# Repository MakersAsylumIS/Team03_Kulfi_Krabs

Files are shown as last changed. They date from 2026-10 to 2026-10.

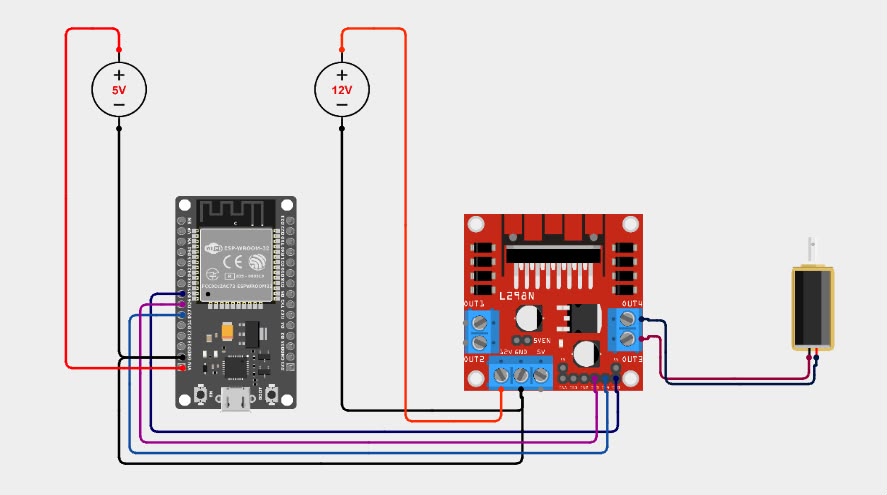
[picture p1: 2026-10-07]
Photos_Videos/Images/WhatsApp Image 2026-10-07 at 11.19.05 AM.jpeg

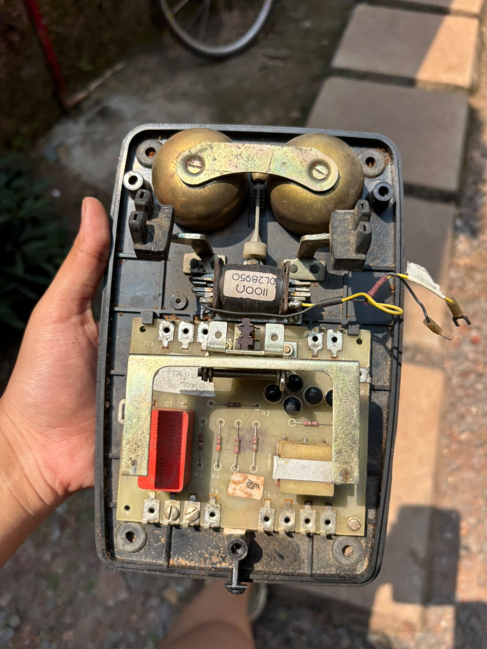
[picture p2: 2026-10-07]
Photos_Videos/Images/WhatsApp Image 2026-10-07 at 11.19.09 AM.jpeg

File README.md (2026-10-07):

# MAKER'S ASYLUM + KULFI Play it Forward (PiF) Partnership
## 2026 Week 40 COHORT 06
## Team : KULFI_RABS

Describe the project.
Describe what are the contents of each folder - CODE, CAD, Electronics etc

## License

Licenses

<a href="LICENSE.md">Open Source Licenses Facts</a>

#### Hardware
CERN Open Hardware License Version 2 - Strongly Reciprocal ([CERN-OHL-S-2.0](https://spdx.org/licenses/CERN-OHL-S-2.0.html)).

#### Software
MIT open source [license](http://opensource.org/licenses/MIT).

#### Documentation:
<br />This work is licensed under a <a rel="license" href="http://creativecommons.org/licenses/by/4.0/">Creative Commons Attribution 4.0 International License</a>.

---

## 📬 Contact/Team

> _List team members and contact emails or GitHub profiles._
[@anool](https://github.com/Anool)
> 
>
> ---

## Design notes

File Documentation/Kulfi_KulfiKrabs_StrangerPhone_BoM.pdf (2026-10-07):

Year | 2026
Cohort | Kulfi Collective
Team Name | Kulfi Krabs
Project Name | Stranger Phone
Team Members | Khushi | Devashree
Email IDs
Team Mentor | Kushal Bhor
Team Mentor

Project Brief:

Sr no | Product name | Qty
| 1 Vintage push-button telephone (Bakelite / BSNL style) with handset, cord, keypad and hook

1

2 12 mm tactile push
buttons (pack of 10)

1

Notes
* Use this template and fill in the details below. Share it back with "editable" link.
* Explain your project in brief

* For all the components (https://robu.in/) that you are ordering online provide the reference link of the online store from where you are
* For the components that you are planning to purchase from your local store provide the reference link of image or video
* DO NOT RELY ON GETTING ANYTHING FROM THE LOCAL STORE HERE IN GOA. YOU WON'T HAVE THE TIME, MEANS OR AVAILABILITY TO GET THE COMPONENTS FROM THE LOCAL STORE
A vintage push-button telephone mounted inside a Mumbai kaali-peeli cab. A passenger picks up the handset, chooses a language (1 English / 2 Hindi / 3 Marathi), hears a short description in that language, then presses 4 to hear a message a previous stranger left, or 5 to record one for the next stranger (6 to re-record, 7 to save). Messages are stored on a microSD card by language and played back only to listeners who chose that language. After saving, the passenger taps their phone on an NFC sticker for a small web 'surprise'. Built on an ESP32-A1S Audio Kit (records + plays audio, SD card, onboard keys); powered by a power bank. Pillars from fieldwork: empathy, connection, time.

3 Micro limit switch
with lever (2 pcs)

1

4 Ai-Thinker ESP32-A1S
Audio Kit v2.2
(ES8388 codec,
microSD, 6 keys,
headphone + speaker

2

5 microSD card 32 GB
Class 10 (HP mi210)

1

6 USB microSD card
reader

1

7 MAX9814 microphone
amplifier module
with electret
capsule (AGC)

2

8 Electret microphone
capsule 6 mm / 9 mm
(pack of 10)

1

9 Resistor assortment
kit (1/4 W, 50
values, 500 pcs)

1

10 3.5 mm AUX male-tomale cable (cut in
half for two
solderable plugs)

1

11 Mini speaker 8 Ohm
0.5 W, 28 mm (2 pcs)

1

12 4-core flexible
cable, 1 m (or spare
coiled handset cord)

1

13 NFC sticker tags
NTAG213 (pack of 10)

1

14 Power bank 10,000
mAh (EVM EnBolt
22.5W)

1

15 Micro-USB DATA
cable, 1.5 m (2 pcs)

1

16 Hookup wire 22 AWG,
5 colours x 2 m

1

17 Female-female Dupont
jumper wires, 20 cm
(40 pcs)

1

18 Male pin header
strip 2.54 mm (1 pc,
40 pins)

1

19 Heat-shrink tubing
assortment

1

20 Hot glue sticks (10)
+ double-sided foam
tape

1

21 Acrylic base plate
200 x 200 x 3 mm +
4x M4 bolts/nuts +
cable ties

1

22 Rubber grommet 8-10
mm (2 pcs)

1

Prices and stock checked on 25 Sep 2026 (Probots, Robu, Amazon.in): every link is a direct product page that was IN STOCK at the time of checking. Phone price depends on Chor Bazaar bargaining and is the lever if the total runs over. Online orders placed by 26 Sep reach Mumbai by 29 Sep (use the Mumbai pincode at checkout, not Goa). Nothing is being bought in Goa.

TOOLS TO CARRY (owned / borrowed, not purchased - add ~Rs 1,500 if any must be bought)
- Soldering iron (25-40 W) + solder + flux
- Wire stripper / cutter
- Multimeter (continuity for hook switch + keypad tracing)
- Small screwdriver set (phone screws) + hand drill or drill bits for the base plate
- Hot glue gun
- Laptop with Arduino IDE, ESP32 board package, arduino-audio-tools library and CP210x USB driver installed and tested BEFORE leaving
- NFC-capable phone with the 'NFC Tools' app (to write the URL to the tags)

PREP BEFORE GOA (the flowchart cannot run without these - no purchase needed)
- Record the prompt files as 16 kHz mono WAV: ask_lang (trilingual, 1 file) + for EACH of en/hi/mr: desc, menu, heres, none_yet, rec_intro ('record your message in <language> after the beep'), review (6/7), last_take, saved, surprise, goodbye, plus beep.wav = 32 files

- Record 5+ seed messages per language into archive/en, archive/hi, archive/mr so the first listener never hears 'no messages yet'
- Build and host the surprise web page (he/she/they -> emoji + cab location + time); free hosting (GitHub Pages / Netlify); write its URL with cab number to the NFC tags
- Flash and test the firmware on the bench with the full flow (language -> description -> listen / record -> 6 / 7 -> save -> hang-up resets to idle) before packing -including the power-bank keep-alive: Wi-Fi radio left on + 47 ohm resistor across 5V/GND, then leave it running on the bank overnight to prove the bank does not switch off
- Pre-drill the base plate; pack the spare board, spare SD card (pre-loaded) and spare mic module

Angad

Category | Purpose | Reference link
Electro-mechanical | Flow: 'Picks up the
| phone', keys 1-7,
| 'Hangs up'. Shell,
| handset (mic +
| earpiece), keypad, | https://www.olx.in/i
| | tems/q-vintage-
| | telephone (https://www.olx.in/items/q-vintage-telephone)
Electronics | Flow: keys 1-7. BACKUP: most push- button phones have a printed keypad matrix that cannot

https://robu.in/prod
uct/12x12x12mmtactile-push-buttonswitch-10pcs/ (https://robu.in/product/12x12x12mm-tactile-push-button-switch-10pcs/)

Electro-mechanical Flow: 'Picks up' / 'Hangs up'. BACKUP hook switch if the phone's original cradle contacts are

https://robu.in/prod
uct/kw1-103-z2a100-
spdt-short-levermicro-switch1n/ (https://robu.in/product/kw1-103-z2a100-spdt-short-lever-micro-switch1n/)
Electronics | The brain for every node: plays language/description /menu/record/review/ saved prompts from

https://probots.co.i
n/esp32-a1s-audiodevelopment-boardkit-ai-thinkerwifi.html (https://probots.co.in/esp32-a1s-audio-development-board-kit-ai-thinker-wifi.html)
Electronics | Flow: every prompt file (prompts/en, hi, mr) and the message archive (archive/en, hi,

https://www.amazon.i
n/dp/B07DJLFMPS (https://www.amazon.in/dp/B07DJLFMPS)
Electronics | Loading the 15 prompt WAV files and seed messages onto the SD card from a laptop, and pulling

https://www.amazon.i
n/dp/B0D9H3W8V6 (https://www.amazon.in/dp/B0D9H3W8V6)
Electronics | Flow: '(person records message)'. Sits inside the handset mouthpiece; AGC evens out

https://robu.in/prod
uct/max9814-highperformancemicrophone-agcamplifier-module-cma- (https://robu.in/product/max9814-high-performance-microphone-agc-amplifier-module-cma-4544pf-w/)
Electronics | FALLBACK mic: if the MAX9814 signal is too hot or noisy, a bare capsule soldered straight to

https://w (https://robu.in/product/max9814-high-performance-microphone-agc-amplifier-module-cma-4544pf-w/)ww.amazon.i
n/Yellow-Tommy-Condenser-Microphone-Directional/dp/B0GTQ
Z9ZNK (https://www.amazon.in/Yellow-Tommy-Condenser-Microphone-Directional/dp/B0GTQZ9ZNK)
Electronics | 10 kOhm pull-up for key 1 on IO36 (input- only pin); 10k/1k divider between MAX9814 and MIC1;

https://www.amazon.i
n/dp/B0D6LRHHVZ (https://www.amazon.in/dp/B0D6LRHHVZ)
Electronics | Flow: every 'hears' node. Carries audio OUT of the board's 3.5 mm headphone jack to the handset

https://robu.in/prod
uct/aux3-5mm-audioextension-cable-2mmale-to-male-grey/ (https://robu.in/product/aux3-5mm-audio-extension-cable-2m-male-to-male-grey/)

Electronics | Replacement earpiece only if the phone's original earpiece is dead. Driven from the headphone jack.

https://robu.in/prod
uct/0-5w-8ohmtrumpet-speakerdiameter-28mm/ (https://robu.in/product/0-5w-8ohm-trumpet-speaker-diameter-28mm/)
Electronics | BACKUP handset cord: mic V+, mic signal, earpiece, shared ground. Old coiled cords are often

https://robu.in/prod
uct/22awg-multicoreinsulated-cable4-
cores-silicone/ (https://robu.in/product/22awg-multicore-insulated-cable4-cores-silicone/)
Electronics | Flow: 'Taps on the NFC tag'. Stuck on the phone body; holds the URL of the surprise web page

https://www.amazon.i
n/Robodo-Sticker-13-
56MHz-ISO14443A-Ntag213/dp/B07DDDGT1
L (https://www.amazon.in/Robodo-Sticker-13-56MHz-ISO14443A-Ntag213/dp/B07DDDGT1L)
Electronics | Powers the board in the cab via micro- USB; driver swaps/charges it. Must NOT auto-shut-

https://www.amazon.i
n/dp/B0H1QCZ87F (https://www.amazon.in/dp/B0H1QCZ87F)
Electronics | One for programming the board from a laptop, one from the power bank in the cab.

https://www.amazon.i
n/dp/B082LZGK39 (https://www.amazon.in/dp/B082LZGK39)
Electronics | Wiring the 7 keys + hook switch to IO36, IO13, IO19, IO23, IO18, IO5, IO21, IO22 and the handset

https://www.amazon.i
n/dp/B0H8358SGS (https://www.amazon.in/dp/B0H8358SGS)
Electronics | Quick connections from the board's pin header to the switch wires during testing.

https://robu.in/prod
uct/20cm-dupont-wirecolor-jumper-cable-2-
54mm-1p-1p-female-female-40pcs/ (https://robu.in/product/20cm-dupont-wire-color-jumper-cable-2-54mm-1p-1p-female-female-40pcs/)
Electronics | In case the A1S header pins arrive unpopulated or you need extra pins to solder to.

https://robu.in/prod
uct/2-54mm-1x40-pinmale-single-rowstraight-long-headerstrip-pack-of-3/ (https://robu.in/product/2-54mm-1x40-pin-male-single-row-straight-long-header-strip-pack-of-3/)

Misc | Insulating every solder joint on the handset and keypad wiring.

https://www.amazon.i
n/dp/B08S3TP2Q6 (https://www.amazon.in/dp/B08S3TP2Q6)
Misc | Fixing the board, mic module and SD card inside the phone shell so nothing rattles in

https://www.amazon.i
n/dp/B0FD456NSD (https://www.amazon.in/dp/B0FD456NSD)
Mechanical | Mounts the phone in the cab: phone screws to the plate, plate cable-ties to the seat frame /

https://www.amazon.i
n/dp/B0DPV3BKWF (https://www.amazon.in/dp/B0DPV3BKWF)
Mechanical | Where the power cable exits the phone base.

https://www.amazon.i
n/Rebower-Rubber-Grommets-Flexible-Wire/dp/B0BN472J62 (https://www.amazon.in/Rebower-Rubber-Grommets-Flexible-Wire/dp/B0BN472J62)

Additional details | Cost
LOCAL: Chor Bazaar (Mutton St) or OLX Mumbai. Test hook switch, keypad and earpiece before buying. Buy by 28 Sep. | Rs 2,500

Robu pack of 10, Rs 49, in stock (checked 25 Sep).

Rs 49

Robu KW1-103 short-lever, Rs 14 each, in stock (checked 25 Sep). Order 2.

Rs 28

In stock at Probots, Rs 2,499 each, dispatch 1 working day, 1-3 day express to Mumbai. Alt: Amazon.in 'ESP32-Audio-Kit ESP32-A1S' (Rakstore / JESSINIE). ORDER BY 26

Rs 4,998

Amazon.in HP 32 GB Class 10 U1, Rs 899, in stock (checked 25 Sep). Card prices are high online right now - a local mobile shop is ~Rs 400-500; buy the 2nd (spare) card there if

Rs 899

Amazon.in Digitek DCR-007, USB-A 3.0 + Type-C, Rs 299, in stock (checked 25 Sep).

Rs 299

Robu Rs 191 each, in stock (checked 25 Sep). Alt:
https://www.sunrom.com/p/max9814-microphone-amplifier-agc-auto-gaincontrol . Order by 26 Sep.

Rs 382

Amazon.in Yellow Tommy pack of 10, Rs 249 (team-verified listing). Same capsule type also on Lamington Road.

Rs 249

Amazon.in AVS 500 pc assorted kit, Rs 199, in stock (checked 25 Sep). Robu resistor kits were all out of stock. Also cheap at Lamington Road.

Rs 199

Robu AUX 2 m cable, Rs 279-299, in stock - but overpriced. Any Rs 60-100 aux cable from a mobile shop / Lamington Road does the same job. Cut in half = two solderable plugs.

Rs 60

Robu 28 mm 0.5 W 8 ohm, Rs 39, IN STOCK (checked 25 Sep). Buy 2: one spare earpiece, one bench test speaker. The 36 mm version is out of stock.

Rs 78

Robu 22 AWG 4-core silicone cable, Rs 87 per metre, IN STOCK (checked 25 Sep). The 26/24/30 AWG versions are out of stock.

Rs 87

Amazon.in Robodo 10-pack. Alt in stock at Robu, Rs 29 per tag (checked 25 Sep):
https://robu.in/product/13-56-mhzntag213-144byte-sticker-nfc-tag/ .

Rs 300

Amazon.in EVM EnBolt 10000 mAh, Rs 749, in stock (checked 25 Sep). No low-current mode - so firmware keeps Wi-Fi on + a 47 ohm 1 W keep-alive resistor across 5V/GND (from the

Rs 749

Amazon.in Ambrane 3A braided micro-USB DATA cable 1.5 m, Rs 149, in stock (checked 25 Sep). Order 2 (one for programming, one for the cab).

Rs 298

Amazon.in SixOhms 22 AWG solid-core kit, 5 colours x 2 m, Rs 99, in stock (checked 25 Sep). Robu hook-up wire kits are out of stock / Rs 800+. Lamington Road sells by the

Rs 99

Robu 20 cm F-F 40 pcs, Rs 44, in stock (checked 25 Sep). The M-M/M-F/F-F combo pack is out of stock.

Rs 44

Robu pack of 3, Rs 15, in stock (checked 25 Sep).

Rs 15

Amazon.in Rpi Shop 80 pc assorted kit, Rs 165, in stock (checked 25 Sep). Robu alt in stock:
https://robu.in/product/colorfulheat-shrink-tubing-hst-insulation-

Rs 165

Amazon.in ProKart 7 mm glue sticks, 10 pcs, Rs 72, in stock (checked 25 Sep). Add double-sided foam tape from any stationery shop (~Rs 60).

Rs 132

Amazon.in black acrylic 200 x 200 x 3 mm, Rs 203, in stock (checked 25 Sep). M4 bolts/nuts + cable ties from any hardware shop (~Rs 100). Pre-drill before Goa.

Rs 303

Amazon.in Rebower 8 mm grommets, 20 pcs. Any hardware shop also has these.

Rs 20

TOTAL | Rs 11,953
Budget | Rs 12,000
Remaining | Rs 47

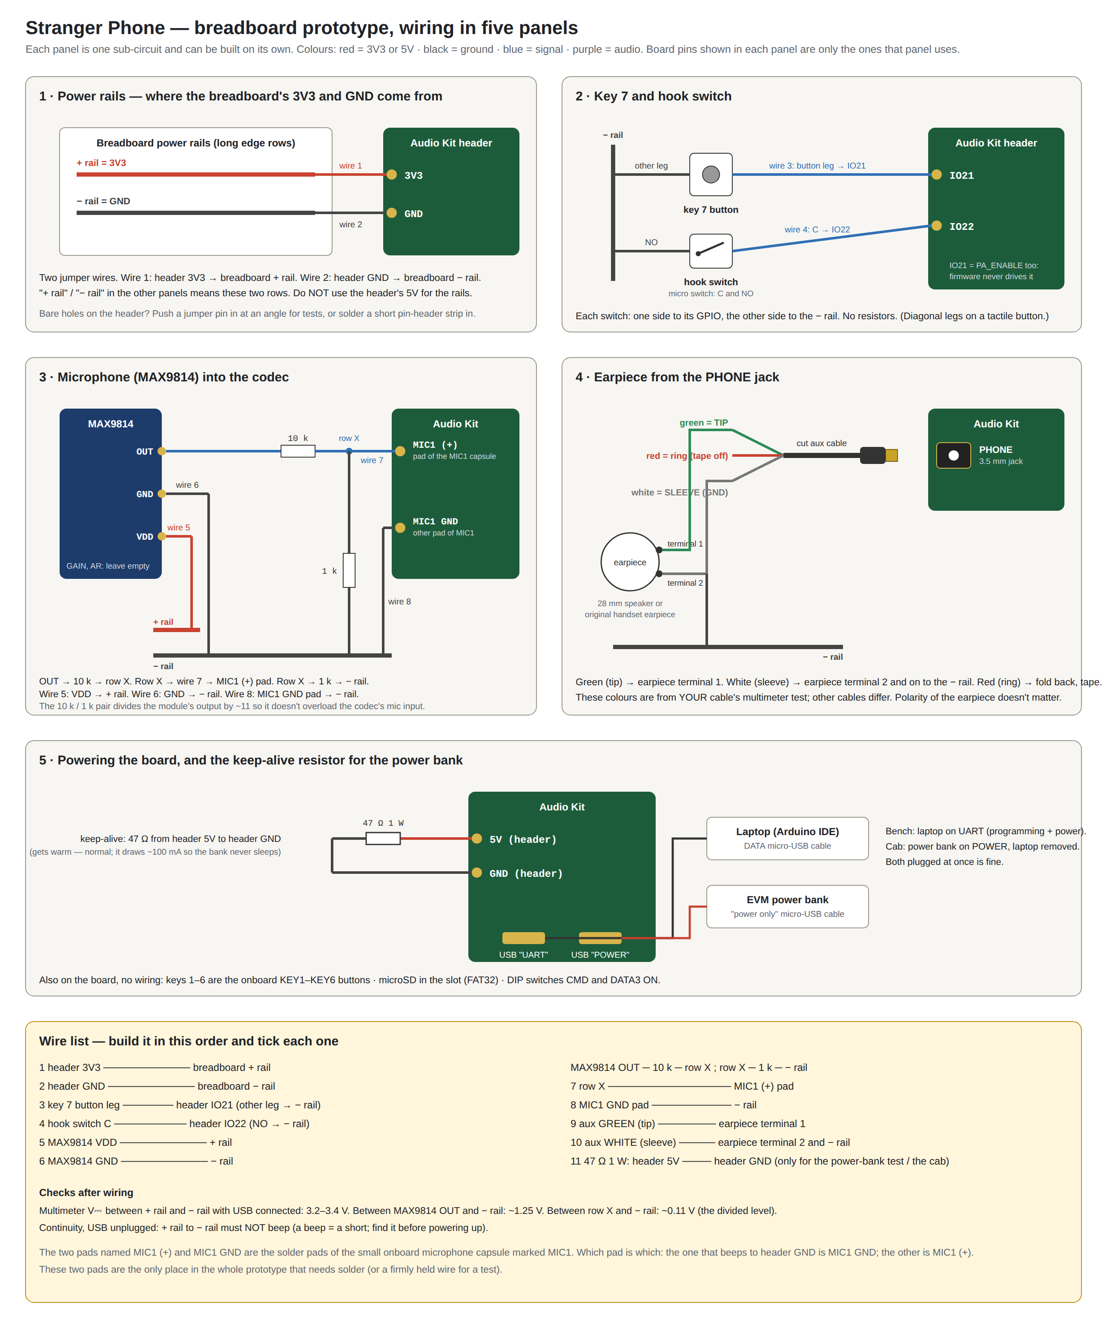
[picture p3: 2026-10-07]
Documentation/StrangerPhone_breadboard_schematic_v2.png

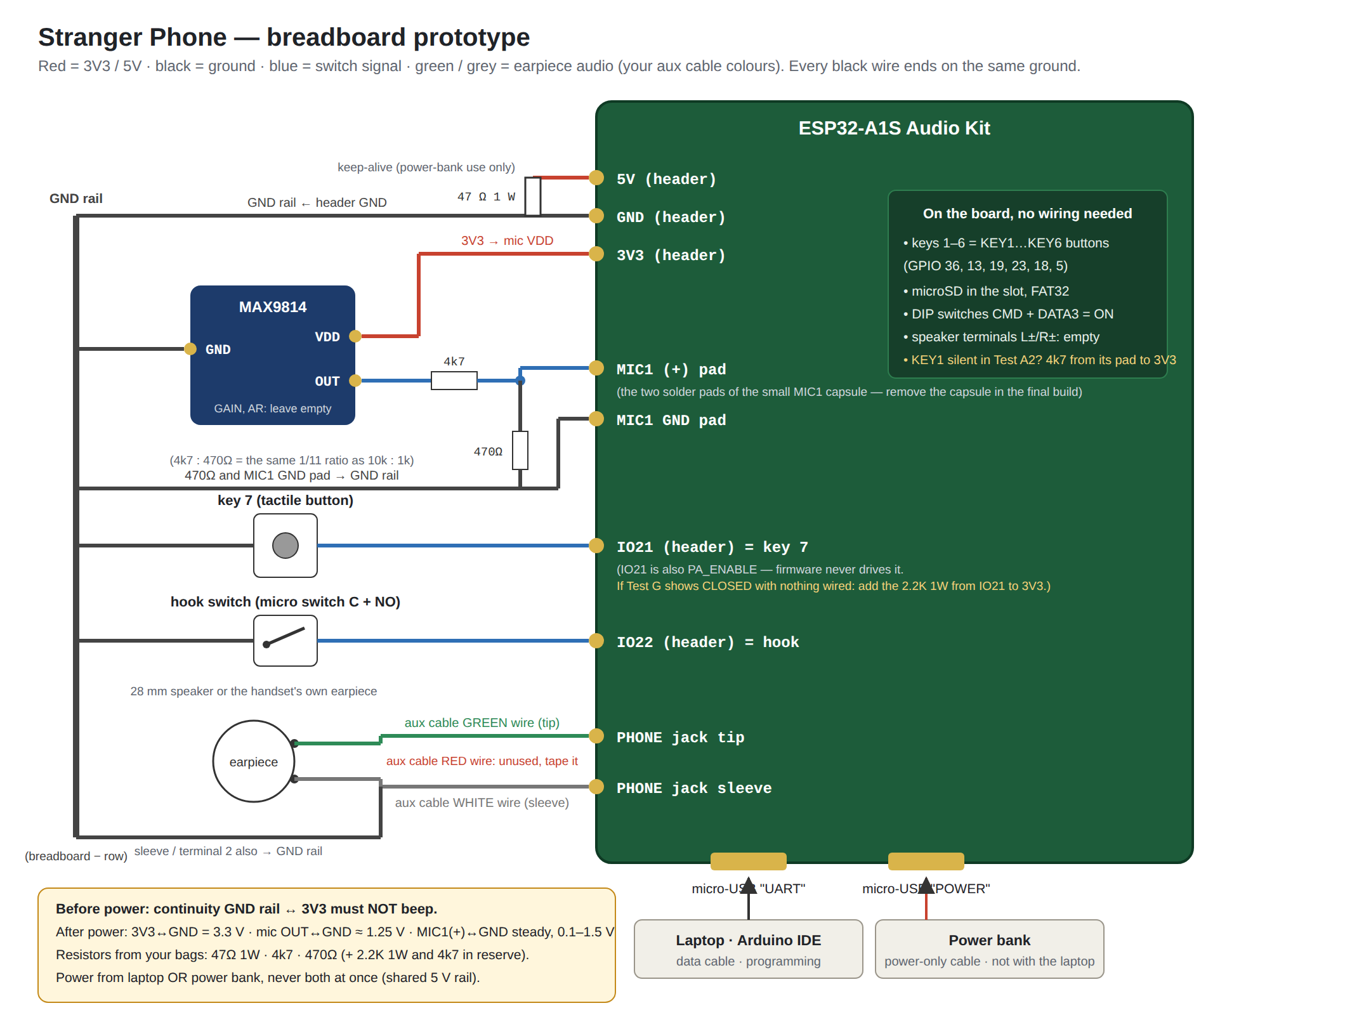
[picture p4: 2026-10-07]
Documentation/StrangerPhone_schematic_clean.png

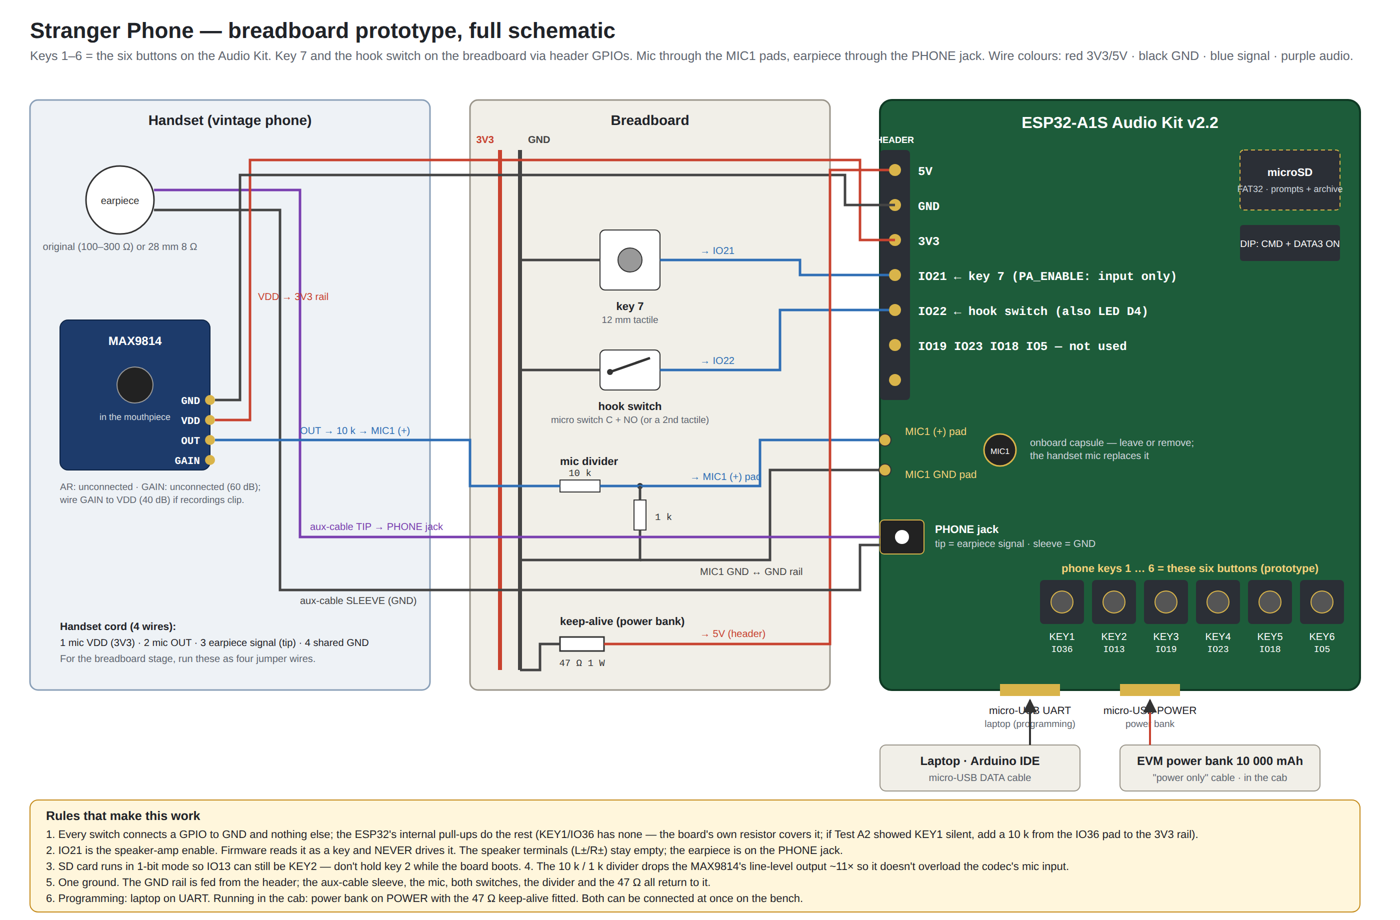
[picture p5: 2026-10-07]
Documentation/StrangerPhone_breadboard_schematic.png

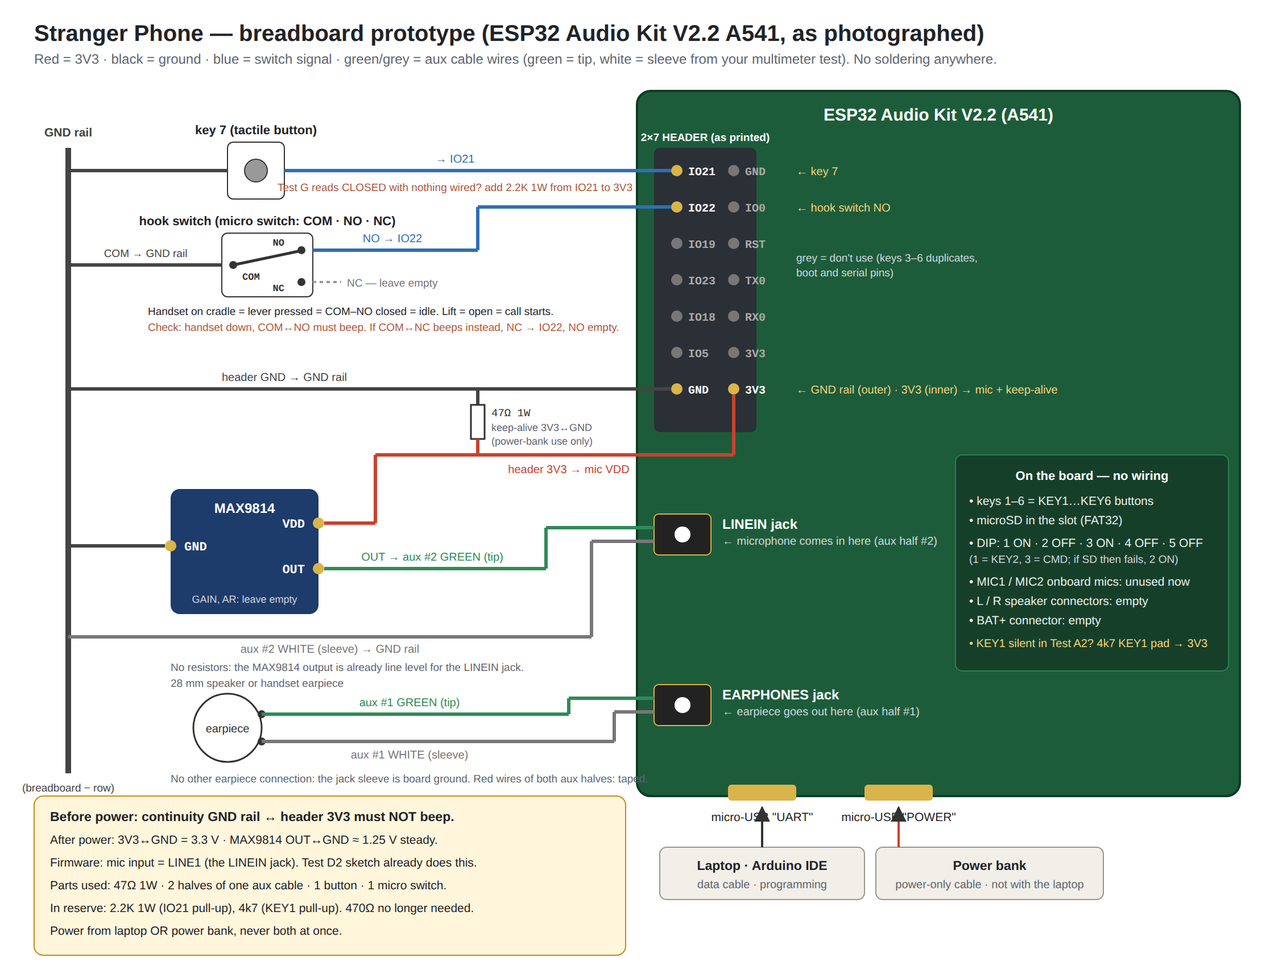
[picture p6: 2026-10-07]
Electronics/01_Full_prototype_schematic_A541_board.png

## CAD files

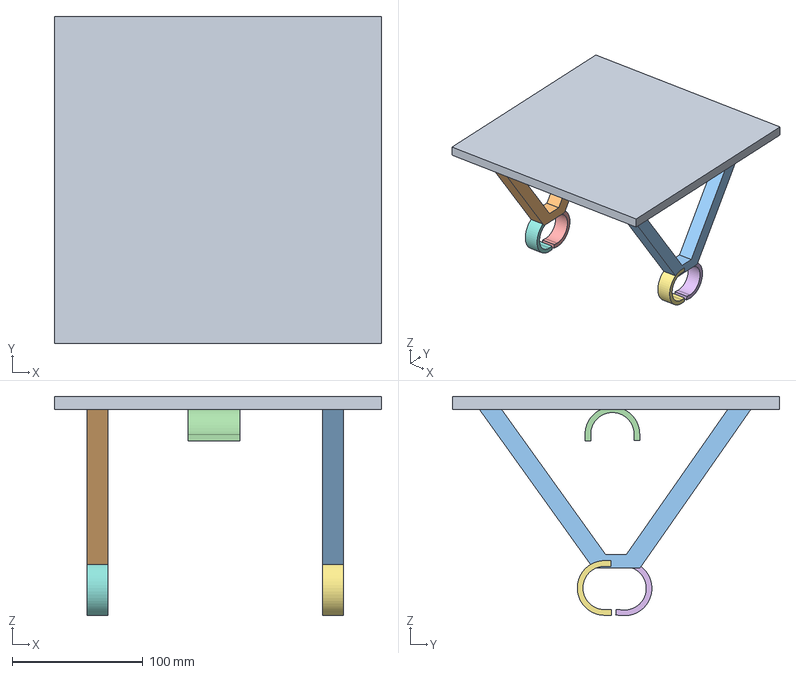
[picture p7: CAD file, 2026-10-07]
CAD/stand.FCStd
250.0 x 250.0 x 167.7 mm
1 stand
1 stand001
clasp
clasp001
clasp002
clasp003
clasp004

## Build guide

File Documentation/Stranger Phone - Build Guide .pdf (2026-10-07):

# The Stranger Phone

Build guide and bill of materials — a vintage phone in a kaali-peeli that plays and records messages between strangers
Play It Forward residency · Kulfi Collective · September 2026

## 1. Concept recap

A vintage rotary or push-button telephone is mounted inside a Bombay kaali-peeli cab. A passenger notices a phone that clearly should not be there, picks up the handset, and an automated voice says "A stranger left a message for you", then plays a message recorded by a previous passenger. The voice then says "To leave a message for a stranger, press 1." Pressing 1 records the passenger's own message, which is added to the pool for future strangers.

The build rests on three pillars from the fieldwork: empathy (hearing a real stranger's voice), connection (a moment of contact in an otherwise isolated commute), and time (turning passive, zombie-like transit time into something meaningful).

## 2. How it works

Keep the vintage phone's shell, handset, cord and hook switch. Remove its original internals and put a small computer inside that does four things: notices when the handset is lifted, plays audio into the earpiece, records audio from the mouthpiece, and notices a "1" press. Everything else is software.

### Hardware overview

The phone. A rotary or push-button Bakelite-style phone from Chor Bazaar or OLX. Push-button makes "press 1" trivial; rotary is more charming and still workable — dialling 1 sends exactly one pulse, which is counted on a GPIO pin. Only the shell, handset, cord and hook switch matter.

The brain. A Raspberry Pi Zero 2 W runs Python, plays and records audio, and sips power. A Pi 4 gives headroom for on-device speech-to-text or a web dashboard but roughly triples power draw.

Audio in/out. The Pi has no mic input, so a USB sound card (simplest) or an I2S audio HAT is added. Old handsets use a carbon microphone that will not work with modern inputs, so the mouthpiece capsule is swapped for an electret capsule. The earpiece speaker usually works as-is and is driven through a tiny PAM8403 amplifier so it is loud enough over cab noise.

Switches. The hook switch wires to one GPIO pin with a pull-up resistor. On a push-button phone the keypad matrix is scanned from a few GPIO pins, or the "1" key alone is wired as a single button. On a rotary phone one GPIO counts pulses.

Power. Two options, detailed in Section 4: a power bank (no wiring into the cab, no permissions, the driver swaps or charges it), or the cab's cigarette-lighter socket through a UPS HAT so the Pi survives ignition on/off cycles. In both cases the Pi's filesystem is set to read-only overlay mode with a separate writable partition for messages, so hard power cuts do not corrupt the SD card.

Mounting. Vibration and theft are the real enemies. Bolt the phone base to the dashboard or centre-console cover, or to a small plywood plate cable-tied to the seat frame, and keep the Pi in a case inside the phone body. The driver is the caretaker.

### Software

Raspberry Pi OS Lite and a single Python script that is essentially a state machine:

- Idle → handset lifted (GPIO) → play greeting ("A stranger left a message for you")
- Pick one message from the local folder (random, or oldest-unheard) and play it
- Play prompt ("To leave a message for a stranger, press 1") and wait up to ~8 seconds for a 1
- Beep, record until hang-up, silence, or 60 seconds
- Play "Your message will find a stranger" and return to idle on hang-up
- Hanging up at any point stops everything and resets

Libraries: gpiozero for the hook and button, sounddevice or plain arecord/aplay for audio, pydub for trimming silence and normalising volume so quiet whispers and loud passengers sound similar. Prompts should be pre-recorded WAV files, not live text-to-speech — record them with a real human voice in Hindi, Marathi and English (or generate once and save), so nothing needs internet in the cab. Seed the phone with 15–20 messages recorded by the team and friends before it goes into a cab, so the very first passenger has something to hear.

### Two decisions to make early

Moderation. Messages recorded by strangers will be played to strangers, so a buffer is needed. Simplest: new recordings land in a "pending" folder and only move to "approved" after someone on the team listens. With a phone hotspot or 4G dongle the Pi can upload recordings to a small server (Supabase, Firebase or a plain VPS) for browser-based approval; this also lets multiple cabs share one pool of messages and provides data for the showcase. Whisper transcription plus a text filter on the server can auto-flag the obvious cases.

Noise. Kaali-peeli cabs are loud. The handset's shape helps because the mouthpiece sits close to the mouth; add a noise gate in software and cap message length. Test in a moving cab early, not on a desk.

### Fallback build

If the Pi route stalls: hide an old Android phone inside the vintage shell and wire the handset as a wired headset through a TRRS jack — earpiece and electret mic on the audio lines, hook switch wired like the headset play/pause button. A kiosk-mode web app does the rest, and battery, charging, 4G and a mic amp come for free. Less "hardware", but a two-evening build and a solid plan B before Goa.

### Showcase tie-in

The Pi can log every play and record event, so a TouchDesigner visual at the showcase — a slowly growing map of message-to-stranger connections, or a live feed of message waveforms — lets visitors see the connection pillar, not just hear it.

## 3. Bill of materials — shared parts (both options)

Prices are approximate Indian street prices (Robu.in, Amazon.in, Lamington Road) as of September 2026 — check current listings before ordering.

# | Item | Qty | Approx. ₹ | Notes / source

1 | Vintage rotary or push-button phone (working handset, cord, hook switch) | 1 | 1,500–4,000 | Chor Bazaar / OLX. Push-button is easier for "press 1"
2 | Raspberry Pi Zero 2 W (with header pins soldered) | 1 | 2,400–2,800 | Robu.in / Amazon.in
3 | microSD card, 32 GB, A1-class | 1 | 400–600 | SanDisk / Samsung
4 | USB sound card (mic in + headphone out) | 1 | 300–800 | Any CM108-based dongle works
5 | Micro-USB OTG adapter (Pi Zero → USB-A) | 1 | 100–150 | For the sound card
6 | Electret mic capsule, 6 mm, with leads | 2 | 50 each | One spare. Replaces the carbon mic in the mouthpiece
7 | PAM8403 mini amplifier module | 1 | 80–120 | Drives the earpiece from the sound card headphone out
8 | 10 kΩ resistors (pull-ups), 100 nF capacitors (debounce) | few | 50 | Lamington Road assorted pack
9 | Tactile push button 12 mm (only if wiring a single "1" button instead of the keypad) | 2 | 30 | Optional
10 | 3.5 mm TRRS breakout or two 3.5 mm plugs | 2 | 80 | Connects handset wiring to the sound card
11 | Dupont jumper wires + hookup wire (22 AWG) | 1 set | 150
12 | Heat-shrink tubing, small assorted | 1 | 80
13 | Double-sided foam tape / hot glue sticks
1 | 100 | Mounting the Pi and boards inside the shell
14 | Small plywood/acrylic base plate + M4 bolts, cable ties | 1 | 300 | Mounting the phone in the cab
15 | Micro-USB cable, right-angle, 1 m | 1 | 150 | Pi power lead
| Shared subtotal | | ≈ 6,000–9,500

Tools needed but not per phone: soldering iron and solder (~₹600), multimeter (~₹500), wire strippers, a small screwdriver set.

## 4. Power options

### Option A — Power bank

# | Item | Qty | Approx. ₹ | Notes / source

A1 | Power bank, 20,000 mAh, with low- current / "always-on" mode | 1 | 1,500–2,500 | Critical: many banks auto-shut-off below ~100 mA, and an idle Pi Zero sits at that threshold. Look for "trickle charge", "low-current mode" or "always on" (Anker, some Ambrane / Stuffcool models)

# | Item | Qty | Approx. ₹ | Notes / source

A2 | Power bank, 10,000 mAh, same requirement (spare / swap unit) | 1 | 800–1,200 | Lets the driver swap rather than wait for a charge
A3 | Short USB-A → micro-USB cable, 30 cm | 1 | 100 | Keeps the bank inside or under the phone
A4 | Velcro strap / small pouch to hold the bank | 1 | 100
Option A subtotal | ≈ 2,500–3,900
Option A total per phone | ≈ 8,500–13,400 | Shared parts + Option A

Expected runtime: the Pi Zero 2 W plus sound card and amp averages roughly 1–1.5 W, so a 20,000 mAh bank (~60 Wh usable) gives about 40–55 hours — two working days between charges. Set the Pi to a read-only overlay filesystem so a bank running flat does not corrupt the card. No wiring into the cab means no permissions and no driver hesitation.

### Option B — Cigarette-lighter supply + UPS

# | Item | Qty | Approx. ₹ | Notes / source

B1 | Car cigarette-lighter USB adapter, 5 V ≥ 2.4 A (dual port is handy) | 1 | 300–700 | Branded (Portronics, Anker, Baseus); no-name ones put noise on the audio line
B2 | Waveshare UPS HAT (C) for Pi Zero | 1 | 2,000–2,600 | Sits under the Pi Zero, USB-C input, powers the Pi and charges the cell simultaneously; reports battery level over I2C
B3 | 18650 Li-ion cell, 2,600–3,400 mAh, protected (Samsung / LG / Molicel) | 1 | 300–500 | Goes into the UPS HAT holder. Buy from a reputable seller
B4 | USB-A → USB-C cable, 1.5–2 m | 1 | 200–300 | Lighter socket to UPS HAT; route along the dash edge
B5 | Female / stacking header for Pi Zero | 1 | 60 | Only if the Pi Zero came without one
B6 | Cable clips / spiral wrap for the cable run | 1 | 100
B7 | Inline USB fuse | — | — | Not needed — the lighter adapter is already fused
| Option B subtotal | | ≈ 3,000–4,300
| Option B total per phone | | ≈ 9,000–13,800 | Shared parts + Option B

The 18650 cell in the UPS HAT gives roughly 8–10 hours of standalone runtime, so the phone keeps working when the driver stops for chai or the engine is off, and the Pi never sees a hard power cut when the ignition cycles. The UPS also allows a scripted clean shutdown when the cell drops below ~10 %. A plain 12 V→5 V buck module plus a pass-through power bank is a cheaper alternative, but it brings back the auto-shut-off problem from Option A, so the HAT is the cleaner route.

Practical note: some older kaali-peelis have a dead or unreliable lighter socket. Check the specific cab before committing — if it is dead, Option A is the fallback, and since the two builds differ only in the power section, nothing else changes.

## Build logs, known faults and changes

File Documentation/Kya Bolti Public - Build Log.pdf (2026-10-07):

# Kya Bolti Public

### A phone in a Mumbai kaali-peeli that lets strangers leave each other messages

Build log: what we made, how we made it, and what changed along the way

Team Kulfi Krabs — Khushi, Devashree, Angad Mentor: Kushal Bhor
Kulfi Collective — Play It Forward residency October 2026

## 1. The idea

Kya Bolti Public is a vintage push-button telephone mounted inside a Mumbai taxi. A passenger who picks up the handset hears a short introduction, then a message left by a stranger who sat in the same seat before them. They can keep listening to more strangers, or press a key and leave a message of their own for whoever comes next. The phone is self-contained: no internet, no screen, no attendant. It lives on a power bank and a micro-SD card.

The project rests on three pillars we set at the start: empathy (hearing a stranger’s voice, not a text), connection (the message you leave will be heard by someone you will never meet) and time (the archive grows ride by ride, so the phone slowly becomes a record of the city talking to itself).

## 2. How the call works

The user flow went through several versions before it settled. The version we are building is below; the changes that led to it are in section 8.

- Lift the handset. The phone asks the passenger to pick a language: 1 English, 2 Hindi, 3 Marathi. If nobody presses anything for ten seconds it asks once more, then defaults to Hindi.
- A short recorded introduction plays: “This phone connects you to the people of Mumbai…”. There is no choice here.
- A stranger’s message plays, picked at random from the archive. Within one call no message is repeated; once a passenger has heard every message the list resets.
- A single beep marks the end of the message, then the menu: press 4 for another message, press 5 to record your own. Pressing 4 loops back as many times as the passenger likes.
- Pressing 5: “Please record your message after the beep”, a beep, thirty seconds of recording, and a beep to say the time is up. The take plays back, then “Press 6 to save, press 7 to redo”. 7 deletes the take and records again (up to three times); 6, or ten seconds of silence, saves it.
- After saving: “Your message is saved”, “Enjoy the rest of your ride”, and an end-of-call beep. The phone then waits silently for the handset to be put down.
- Hanging up at any point stops everything, deletes any unsaved take and returns the phone to idle. A message only enters the archive when 6 was pressed.

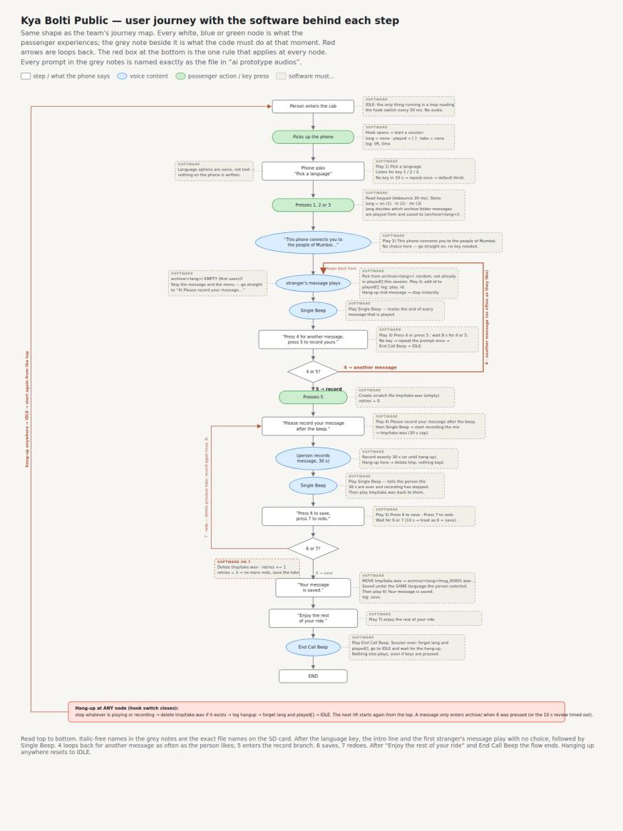
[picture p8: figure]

Figure 1 — The final user journey with the software behind each step (flowchart version 6).

## 3. Hardware

### 3.1 Why the ESP32 Audio Kit

The first plan was a Raspberry Pi: it would have been the easy software path, but it needs a proper shutdown, draws more power than a power bank likes, and brings a Linux boot time to every power cut. We moved to the Ai-Thinker ESP32 Audio Kit V2.2 (board revision A541), which has everything the phone needs on one board: an ESP32-A1S module, an ES8388 audio codec with a line-in jack and a headphone jack, a micro-SD slot, six push buttons and a 2×7 header with a few spare GPIOs. It boots in a second, runs happily from a 5 V power bank and costs a fraction of the Pi route.

### 3.2 What is connected to it

Part | What it does | How it is connected
Vintage telephone handset + cradle | The thing the passenger holds | Earpiece on the EARPHONES jack; hook micro- switch on header pin IO22
Telephone keypad (12 keys, 4×3 matrix) | All passenger input | Seven wires: four rows and three columns to GPIOs (see 3.4)

MAX9814 microphone module | Records the passenger | VDD to header 3V3, OUT to the LINEIN jack tip (and ring), GND to board ground
Micro-SD card (FAT32) | Holds the operator recordings and the archive of messages | Onboard slot, 1-bit mode (DIP 1 ON, 2 OFF, 3 ON, 4 OFF, 5 OFF)
EVM 10,000 mAh power bank | Power in the cab | Micro-USB marked POWER; a 47 Ω 1 W resistor across 3V3–GND keeps the bank from switching itself off
Two halves of one 3.5 mm aux cable | Earpiece and microphone leads | Measured with a multimeter: green = tip, white = sleeve, red = ring

The bill of materials was built in the residency’s template (Kulfi_KulfiKrabs_StrangerPhone_BoM.xlsx), every line with a direct product link checked for stock, and came to ₹11,953 against a ₹12,000 budget.

### 3.3 The hook switch

The cradle switch is a three-terminal micro-switch (COM, NO, NC). COM goes to ground and NO to IO22, so that the handset resting on the cradle holds the pin low and lifting it lets the pin rise. If a cradle happens to work the other way round, NC is used instead, or one setting in the firmware is flipped. Nothing else changes.

### 3.4 The keypad is a matrix

The telephone keypad turned out not to be twelve independent switches but a 4×3 matrix with seven wires. We found this with a multimeter on continuity: every key connects exactly one of wires 1–4 to one of wires 5–7, which makes 1–4 the four rows of keys and 5–7 the three columns. Key 8, for example, is row 3 + column 6. The seven wires go to the seven GPIOs we have (rows on 13, 19, 23, 18; columns on 5, 21, 36), and the firmware scans them the way the multimeter did — pulling one row low at a time and watching the columns. No resistors or diodes are needed because only one key is ever pressed at a time.

To take the keys off the board we solder a wire to the signal-side leg of each onboard button (the board already has a pull-up resistor on every one) and keep a common ground. A short test sketch (Test K) proves each wire reads HIGH at rest and LOW when the external key is pressed.

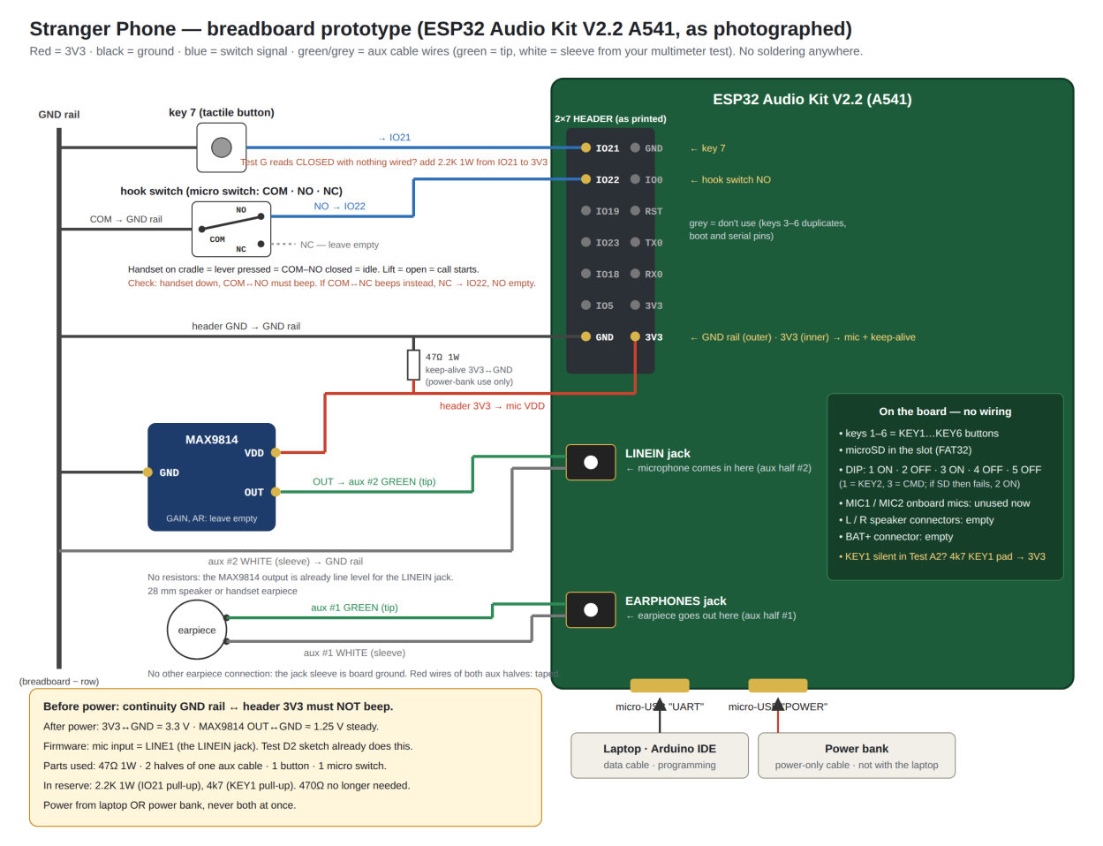
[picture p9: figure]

Figure 2 — The breadboard prototype on the A541 board, drawn against the real header and jacks.

### 3.5 The microphone

The MAX9814 is an electret microphone with its own automatic-gain amplifier, so its output is already at line level and goes straight into the LINEIN jack with no resistors. Early on we planned to solder it to the onboard MIC1 pads through a voltage divider; discovering that the board has a LINEIN jack removed the soldering and the divider in one go. The first working version takes its ground from the earpiece cable’s sleeve, which is board ground at the jack; a cleaner version with its own ground wire from the header and the keep-alive resistor on the same board is drawn for later.

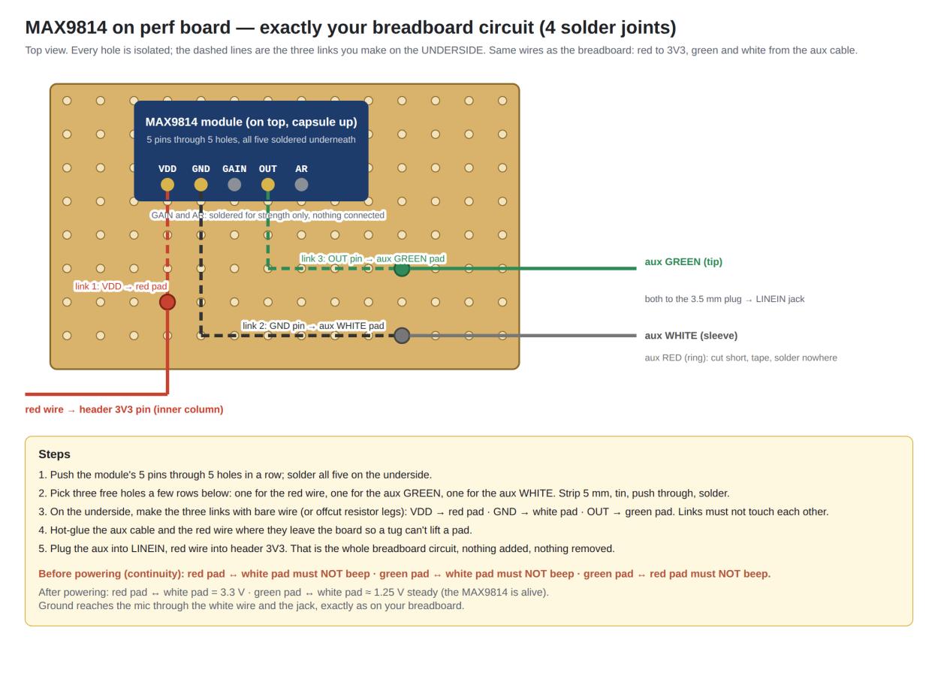
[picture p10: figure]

Figure 3 — Moving the microphone from the breadboard to a perforated board.

## 4. Testing one thing at a time

Rather than wire everything and hope, every part got its own small Arduino sketch with every line commented, so a failure pointed at one component. The tests live in the tests folder:

- A1–A3 the board itself: blink the LED, read the six keys, play a tone through the codec.
- A4 record from the onboard mics to the SD card (later made configurable, because the driver’s naming of the two inputs did not obviously match the board).
- B mount the SD card, list it, write and read a file.
- D / D2 the MAX9814: first a probe test, then recording through the LINEIN jack.
- E, F the electret capsule and the speaker.
- G the hook switch and the IO21 pin (which is also the board’s amplifier-enable line, so the firmware never drives it).
- I the keep-alive resistor on the power bank.
- K one onboard key routed out to the breadboard.
Along the way we learned the Arduino IDE needs the “ESP32 Dev Module” board with the Huge APP partition, that “Hard resetting via RTS pin” is normal, and that the Serial Monitor must be at 115200 baud.

## 5. Firmware

The firmware is one Arduino sketch, KyaBoltiPublic.ino, built on the arduino-audio-tools and arduinoaudio-driver libraries with arduino-libhelix for MP3. The call flow in section 2 is written almost line for line as functions: stepLanguage, stepMessage, stepRecord and session. Every file it plays is named at the top of the sketch exactly as the recording in the ai prototype audios folder, so changing a prompt means replacing a file, not editing code. Every setting a person might want to change — timeouts, volumes, the record length, which input the microphone is on, which way round the hook switch is — is a commented constant at the top.

Strangers’ messages follow one naming rule: any file called User Recording N (MP3 or WAV) counts. Files in the root of the audio folder play for every language; files in the en, hi and mr sub-folders play only to passengers who chose that language, and a new message is saved into the caller’s own language folder, numbered on from the highest number already there. Everything the phone does is written to a log.csv on the card, and the Serial Monitor prints the same lines plus a listing of the files it can see at boot.

Two small tools sit next to the sketch: check_sd_files.py, which checks a local copy of the audio folder for every expected file name and format before the card is copied; and a README describing the card layout.

## 6. Sound

The first recordings sounded poor. Measuring the files showed why: the operator prompts averaged −25 dB while the test messages peaked at −1 dB, so a digital boost that made the prompts audible was clipping the messages hard. All twelve files were normalised with ffmpeg to the same loudness (−16 LUFS, peaks at −1.5 dB), the boost was dropped from 5× to 1.5×, and the originals were kept in an _originals folder. The firmware applies the boost with a hard limiter so a loud take squashes rather than crackles.

## 7. Where things stand

- Working: power, SD card, playback of all prompts, the language step, recording through the MAX9814, the hook switch, the onboard keys, the volume chain.
- In progress: the keypad matrix wiring (continuity map done, soldering next) and the matching scan code; the microphone on perf board; confirming on the Serial Monitor that the three seeded messages are seen on the card.
- Next: final handset wiring off the breadboard, operator recordings in all three languages, the enclosure, and a decision on a battery indicator (a USB power bank hides its charge level, so this is either a run-time estimate on an RGB LED or a move to a bare lithium cell with a fuel-gauge chip).

## 8. Iterations — what changed and why

A short record of the turns, because they explain the shape of what we have.

What | Before | After | Why
Platform | Raspberry Pi | ESP32 Audio Kit V2.2 | Instant boot, power-bank friendly, codec + SD + keys on one board
User flow | Language → description → choose listen or record | Language → intro → message → beep → 4/5 menu loop

The intro is not a decision; listening first makes recording feel natural

Flowchart | Swim-lane diagram | Top-down chart mirroring the team’s own map, with the 4- loop drawn explicitly

The first version was unclear; the loop was missing

Key 6 / 7 meaning | 6 retake, 7 save (code) | 6 save, 7 redo | Matched to the prompt as actually recorded
Audio format | 16 kHz WAV, per-language prompt folders | MP3 prompts, one set, decoder picked by extension | Recordings came as MP3; one voice for the prototype
Beeps | One beep file | Single Beep after every message and after the 30 s, End Call Beep to close | Passenger needs to know the message ended and the recording stopped
End of call | “Tap for a surprise”, wait 60 s | “Enjoy the rest of your ride” → End Call Beep → silence | Simpler ending; surprise moved to a later layer
Message storage | archive/<lang>/msg_00001.wav | User Recording N in the audio folder, with en/hi/mr sub- folders | Team naming; language- specific playback came back as a need
Microphone | MAX9814 soldered to MIC1 pad via a 4k7/470 Ω divider | MAX9814 into the LINEIN jack, no resistors | The board has a line-in jack; no soldering on the board
Keep-alive resistor | 47 Ω ¼ W on 5 V | 47 Ω 1 W on 3V3–GND | ¼ W would burn; the header has no 5 V pin
Hook switch | Two-terminal switch | COM/NO/NC micro-switch, COM to GND, NO to IO22 | The switch we have has three terminals
Keys | Six onboard buttons + one button on IO21

4×3 keypad matrix on seven GPIOs

The vintage keypad is a matrix

Volume | Codec at 80–90 %, then a 5× digital boost | Files normalised, codec at 100 %, 1.5× boost with limiter | Boost was clipping; files were at wildly different levels
Message playback bug | Folder opened with a trailing slash → zero files found | Trailing slash stripped; boot-time file listing added | The phone skipped straight to recording

Each of these is small on its own. Together they are the difference between a plan and a phone that works in the back of a taxi.

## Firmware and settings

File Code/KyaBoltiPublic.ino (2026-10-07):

/*
  KYA BOLTI PUBLIC — firmware for the ESP32 Audio Kit V2.2 (A541, ES8388 codec)
  ================================================================================
  Flow (matches flowchart Version 6):
    IDLE → handset lifted
         → "1) Pick a language"  (1 EN / 2 HI / 3 MR; 10 s, asked twice, default Hindi)
         → "2) This phone connects you to the people of Mumbai."
         → a stranger's message ("User Recording N") → "Single Beep"
         → "3) Press 4 or press 5"   (4 loops back for another message, as often as they like)
         → 5: "4) Please record your message after the beep." → "Single Beep" → RECORD 30 s → "Single Beep"
              → the take is played back → "5) Press 6 to save - Press 7 to redo"
              → 7: delete the take and record again (max 3 redos, then it is saved anyway)
              → 6 (or 10 s silence): save as <lang>/"User Recording <next number>.wav" → "6) Your message is saved"
              → "7) enjoy the rest of your ride" → "End Call Beep" → END (wait for hang-up, nothing else plays)
    no "User Recording" files yet → skip the message and the menu, go straight to recording.
    The language key (1/2/3) picks which messages are heard (that language's folder + the shared root) and
    where a new message is saved. The spoken prompts are one set for now.
    Hang-up at ANY point → stop everything, delete the scratch take, back to IDLE.

  Wiring (StrangerPhone_schematic_A541.png):
    keys 1..6  = onboard KEY1..KEY6   GPIO 36, 13, 19, 23, 18, 5   (to GND when pressed)
    key 7      = header IO21          (to GND when pressed; IO21 is also PA_ENABLE — we never drive it)
    hook       = header IO22          (switch to GND)
    mic        = MAX9814 → LINEIN jack (tip = OUT, sleeve = GND); VDD on header 3V3
    earpiece   = EARPHONES jack (tip + sleeve)
    SD card    = onboard slot, 1-bit mode. DIP: 1 ON, 2 OFF, 3 ON, 4 OFF, 5 OFF
    keep-alive = 47 Ω 1 W between header 3V3 and GND (power-bank use)

  SD card layout — the folder "ai prototype audios" copied AS IS to the root of the card:
    /ai prototype audios/1) Pick a language.mp3
    /ai prototype audios/2) This phone connects you to the people of Mumbai..mp3     (note the double dot — as named)
    /ai prototype audios/3) Press 4 or press 5.mp3
    /ai prototype audios/4) Please record your message after the beep..mp3          (double dot — as named)
    /ai prototype audios/5) Press 6 to save - Press 7 to redo.mp3
    /ai prototype audios/6) Your message is saved.mp3
    /ai prototype audios/7) enjoy the rest of your ride.mp3
    /ai prototype audios/Single Beep.mp3
    /ai prototype audios/End Call Beep.mp3
    /ai prototype audios/User Recording 1.mp3     messages in the ROOT of the folder play for EVERY language (your test ones)
    /ai prototype audios/User Recording 2.mp3
    /ai prototype audios/User Recording 3.mp3
    /ai prototype audios/en/User Recording 1.wav  messages recorded by English callers (key 1) — the phone writes here
    /ai prototype audios/hi/User Recording 1.wav  Hindi callers (key 2)
    /ai prototype audios/mr/User Recording 1.wav  Marathi callers (key 3)
    /tmp/take.wav                         scratch recording (created and deleted by the phone)
    /log.csv                              event log: millis,event,detail,lang
  Everything is MP3 or 16-bit PCM WAV; the firmware picks the decoder from the file extension.
  Messages: any file whose name starts with "User Recording" counts. A caller who chose Hindi hears the
  files in hi/ plus the ones in the root; a new message is saved into the caller's own language folder,
  numbered on from the highest number already there. In one call a message is never repeated; once a
  caller has heard all of them the list resets and they can be heard again.
  Run check_sd_files.py on your local copy of the folder — it verifies names and formats.

  Libraries (Library Manager, all by pschatzmann):
    arduino-audio-tools, arduino-audio-driver, arduino-libhelix (MP3 decoder)
  Board: ESP32 Dev Module · Partition: Huge APP · upload via the micro-USB marked UART.
*/

#include "AudioTools.h"                                   // audio framework: streams, copy loop, WAV codec
#include "AudioTools/AudioCodecs/CodecMP3Helix.h"         // MP3 decoder (needs the arduino-libhelix library)
#include "AudioTools/AudioLibs/AudioBoardStream.h"        // codec driver layer (ES8388 on the Audio Kit)
#include "SD_MMC.h"                                       // ESP32 built-in SD card driver (SDMMC bus)
#include <WiFi.h>                                         // only to keep the radio on for the power bank (keep-alive)

// =============================== SETTINGS YOU MAY CHANGE ===============================
const bool  HOOK_CLOSED_ON_CRADLE = true;   // true: switch contacts are CLOSED (pin LOW) when the handset rests on the cradle.
                                            // Flip to false if the phone behaves as "lifted" while it sits on the cradle.
const input_device_t MIC_INPUT = ADC_INPUT_LINE2;  // LINE2 = the LINEIN jack in this driver (LINE1 = onboard mics). If recordings are silent, try ADC_INPUT_LINE1.
const float VOLUME_PROMPTS   = 1.00;        // codec (hardware) earpiece volume for prompts (0.0 – 1.0, 1.0 = codec maximum)
const float VOLUME_MESSAGES  = 1.00;        // codec volume for strangers' messages and the playback of the user's own take
const float VOLUME_BOOST     = 1.5;         // extra DIGITAL gain applied to every sample before the codec (1.0 = none).
                                            // The audio files are now normalised to the same loudness (check_sd_files.py / ffmpeg),
                                            // so only a little boost is needed. Anything above ~2.0 clips and sounds harsh.
const float MIC_GAIN         = 0.70;        // codec input gain for recording (0.0 – 1.0); lower if recordings clip
const int   RECORD_SECONDS   = 30;          // message length: recording always runs the full 30 s, then Single Beep
const int   LANG_TIMEOUT_MS  = 10000;       // wait for 1/2/3 before repeating the question once
const int   MENU_TIMEOUT_MS  = 8000;        // wait for 4/5 before repeating the menu once
const int   REVIEW_TIMEOUT_MS= 10000;       // wait for 6/7; timeout = treat as 6 (save)
const int   MAX_REDOS        = 3;           // how many times 7 may be pressed; after that the take is saved without asking
const bool  PLAY_TAKE_BACK   = true;        // play the person's own recording back to them before "Press 6 to save - Press 7 to redo"
const bool  KEEP_WIFI_RADIO_ON = true;      // adds ~50 mA so the power bank never thinks the phone is idle
const char* DEFAULT_LANG     = "hi";        // used when nobody presses 1/2/3
// ========================================================================================

// ---- the recordings, named EXACTLY as the files in the folder "ai prototype audios" ----
const char* AUDIO_DIR   = "/ai prototype audios/";                                  // folder at the root of the SD card
const char* PR_LANG     = "1) Pick a language.mp3";                                 // "press 1 / 2 / 3"
const char* PR_INTRO    = "2) This phone connects you to the people of Mumbai..mp3";// the intro line (no choice)
const char* PR_MENU     = "3) Press 4 or press 5.mp3";                              // 4 = another message, 5 = record
const char* PR_REC      = "4) Please record your message after the beep..mp3";      // before recording
const char* PR_REVIEW   = "5) Press 6 to save - Press 7 to redo.mp3";               // after the take has played back
const char* PR_SAVED    = "6) Your message is saved.mp3";                           // after saving
const char* PR_RIDE     = "7) enjoy the rest of your ride.mp3";                     // the last spoken line
const char* SND_BEEP    = "Single Beep.mp3";                                        // after every played message and after the 30 s recording
const char* SND_ENDBEEP = "End Call Beep.mp3";                                      // the very last sound of the call
const char* MSG_PREFIX  = "User Recording ";                                        // strangers' messages: "User Recording 1.mp3", "User Recording 2.wav", ...

// ---- pins ----
const int PIN_KEY[8] = {0, 36, 13, 19, 23, 18, 5, 21};   // index 1..7 = phone keys 1..7 (index 0 unused)
const int PIN_HOOK   = 22;                               // hook switch on header IO22

// ---- codec pin map WITHOUT the PA (IO21), LED (IO22), keys and SD-SPI pins, so the driver never touches them ----
class KBPPins : public audio_driver::DriverDeviceInfo {   // our own pin description for the Audio Kit
 public:
  KBPPins() {                                             // runs once at start-up
    addI2C(PinFunction::CODEC, 32, 33);                   // I2C to the ES8388: SCL 32, SDA 33 (fixed by the board)
    addI2S(PinFunction::CODEC, 0, 27, 25, 26, 35);        // I2S: MCLK 0, BCLK 27, WS 25, DOUT 26, DIN 35 (fixed by the board)
  }                                                       // nothing else: IO21/IO22 stay free for key 7 and the hook
};
KBPPins kbpPins;                                          // the pin map object
audio_driver::AudioBoard kbpBoard(audio_driver::AudioDriverES8388, kbpPins);  // ES8388 driver + our pins
AudioBoardStream kit(kbpBoard);                           // the audio stream we play into and record from

// ---- digital volume boost: multiplies every 16-bit sample by VOLUME_BOOST, with hard limiting, then passes it to the codec ----
class BoostOutput : public AudioOutput {                  // sits between the decoder and the codec
 public:
  BoostOutput(AudioStream& out, float gain) : p_out(&out), gain(gain) {}
  void setAudioInfo(AudioInfo info) override {            // the decoder tells us the file's rate/channels...
    AudioOutput::setAudioInfo(info);
    p_out->setAudioInfo(info);                            // ...and we pass that on to the codec
  }
  size_t write(const uint8_t* data, size_t len) override {  // called with decoded PCM
    size_t done = 0;
    while (done < len) {                                  // work in small chunks so we never need a big buffer
      size_t n = min(len - done, sizeof(buf));
      memcpy(buf, data + done, n);                        // copy (the decoder's buffer is read-only to us)
      int16_t* smp = (int16_t*)buf;                       // our files are 16-bit, so 2 bytes per sample
      for (size_t i = 0; i < n / 2; i++) {
        int32_t v = (int32_t)(smp[i] * gain);             // scale
        if (v > 32767) v = 32767;                         // limit: never wrap around (that is what crackles)
        if (v < -32768) v = -32768;
        smp[i] = (int16_t)v;
      }
      p_out->write(buf, n);                               // on to the codec
      done += n;
    }
    return len;
  }
 private:
  AudioStream* p_out;
  float gain;
  uint8_t buf[512];
};

// ---- session state (reset on every hang-up) ----
String   lang = "";                                       // "en" / "hi" / "mr" once chosen
String   played[64];                                      // message files already played this session
int      playedCount = 0;                                 // how many entries in played[]

// ======================================================================================
//                                   SMALL HELPERS
// ======================================================================================

bool lifted() {                                           // true while the handset is OFF the cradle
  int v = digitalRead(PIN_HOOK);                          // LOW = switch closed, HIGH = switch open
  return HOOK_CLOSED_ON_CRADLE ? (v == HIGH) : (v == LOW);  // translate according to the setting above
}

bool keyDown(int k) {                                     // true while phone key k (1..7) is held
  return digitalRead(PIN_KEY[k]) == LOW;                  // every key shorts its pin to GND when pressed
}

void logEvent(const char* ev, const String& detail = "") {  // append one line to /log.csv on the SD card
  File f = SD_MMC.open("/log.csv", FILE_APPEND);          // open (or create) the log in append mode
  if (!f) return;                                         // no card? skip silently
  f.printf("%lu,%s,%s,%s\n", millis(), ev, detail.c_str(), lang.c_str());  // millis since boot, event, free text, language
  f.close();                                              // close so the line is really on the card
  Serial.printf("[%lu] %s %s\n", millis(), ev, detail.c_str());  // mirror to the serial monitor for debugging
}

String A(const char* name) {                              // full path of one of the operator recordings
  return String(AUDIO_DIR) + name;                        // e.g. "/ai prototype audios/Single Beep.mp3"
}

// Wait up to `timeoutMs` for one of the keys in `allowed` (a string like "45").
// Returns the key number, 0 on timeout, or -1 if the handset was hung up.
int waitKey(const char* allowed, int timeoutMs) {
  unsigned long t0 = millis();                            // remember when we started waiting
  while (millis() - t0 < (unsigned long)timeoutMs) {      // until the timeout...
    if (!lifted()) return -1;                             // hung up → tell the caller to abort
    for (int k = 1; k <= 7; k++) {                        // scan the seven keys
      if (strchr(allowed, '0' + k) && keyDown(k)) {       // this key is allowed AND pressed
        delay(30);                                        // debounce
        if (!keyDown(k)) continue;                        // it was a glitch, keep scanning
        while (keyDown(k)) { if (!lifted()) return -1; delay(10); }  // wait for release so one press = one event
        return k;                                         // report the key
      }
    }
    delay(5);                                             // small pause so the loop isn't a tight spin
  }
  return 0;                                               // nothing pressed in time
}

// ======================================================================================
//                                   AUDIO: PLAY
// ======================================================================================

// Play one file (MP3 or 16-bit PCM WAV) into the earpiece. Returns false if the handset was hung up mid-way.
bool play(const String& path, float volume = VOLUME_PROMPTS) {
  File f = SD_MMC.open(path);                             // open the file on the card
  if (!f) {                                               // missing file?
    Serial.printf("MISSING FILE: %s\n", path.c_str());    // say so in the monitor...
    logEvent("missing", path);                            // ...and in the log, then carry on without it
    return lifted();                                      // treat as "played" unless hung up
  }
  String lower = path; lower.toLowerCase();               // decide the decoder from the extension
  bool isMp3 = lower.endsWith(".mp3");
  Serial.printf("playing %s (%lu bytes, %s)\n", path.c_str(), (unsigned long)f.size(), isMp3 ? "mp3" : "wav");

  auto cfg = kit.defaultConfig(TX_MODE);                  // playback configuration
  cfg.sd_active = false;                                  // we handle the SD card ourselves
  cfg.sample_rate = 16000;                                // starting format — the decoder tells the codec the real one
  cfg.channels = 1;                                       // (our own recordings are 16 kHz mono 16-bit)
  cfg.bits_per_sample = 16;
  kit.begin(cfg);                                         // start the codec for playback
  kit.setVolume(volume);                                  // set the earpiece level

  WAVDecoder wavDec;                                      // decoder for .wav
  MP3DecoderHelix mp3Dec;                                 // decoder for .mp3
  AudioDecoder* dec = isMp3 ? (AudioDecoder*)&mp3Dec : (AudioDecoder*)&wavDec;  // pick one
  BoostOutput boost(kit, VOLUME_BOOST);                   // digital gain stage in front of the codec
  EncodedAudioStream out(&boost, dec);                    // decoded audio → boost → codec; the codec is told the file's rate/channels
  out.begin();                                            // start the decoder
  StreamCopy copier(out, f);                              // copies file bytes into the decoder
  bool ok = true;                                         // assume we finish normally
  while (copier.copy()) {                                 // copy chunk by chunk until the file ends
    if (!lifted()) { ok = false; break; }                 // hang-up → stop immediately
  }
  out.end();                                              // flush the decoder
  f.close();                                              // close the file
  kit.end();                                              // release the codec (next op may be a record)
  Serial.printf("  done%s\n", ok ? "" : " (hung up)");
  return ok;                                              // false only on hang-up
}

// Convenience: play one of the operator recordings by its file name.
bool say(const char* name) { return play(A(name)); }

// ======================================================================================
//                                   AUDIO: RECORD
// ======================================================================================

// Record from the mic into `path` for `seconds`. Returns false if hung up (file is then deleted).
bool record(const String& path, int seconds) {
  SD_MMC.remove(path);                                    // start from a clean file
  File f = SD_MMC.open(path, FILE_WRITE);                 // create the scratch file
  if (!f) { logEvent("error", "cannot create " + path); return false; }  // card problem
  auto cfg = kit.defaultConfig(RX_MODE);                  // recording configuration
  cfg.sd_active = false;                                  // we handle the SD card ourselves
  cfg.input_device = MIC_INPUT;                           // LINEIN jack (see setting at the top)
  cfg.sample_rate = 16000;                                // 16 kHz mono 16-bit
  cfg.channels = 1;
  cfg.bits_per_sample = 16;
  kit.begin(cfg);                                         // start the codec for recording
  kit.setInputVolume(MIC_GAIN);                           // input gain
  WAVEncoder enc;                                         // writes a proper WAV header + samples
  EncodedAudioStream out(&f, &enc);                       // file wrapped in the encoder
  out.begin(cfg);                                         // header gets the right format
  StreamCopy copier(out, kit);                            // copies mic samples into the file
  bool ok = true;                                         // assume normal end
  unsigned long t0 = millis();                            // start time
  while (millis() - t0 < (unsigned long)seconds * 1000UL) {  // until the time limit...
    copier.copy();                                        // ...keep copying audio
    if (!lifted()) { ok = false; break; }                 // hang-up → stop
  }
  out.end();                                              // finalise the WAV header with the real length
  f.close();                                              // close the file
  kit.end();                                              // release the codec
  if (!ok) SD_MMC.remove(path);                           // hung up: nothing is kept
  return ok;
}

// ======================================================================================
//                                   FILE PICKING
// ======================================================================================

// True if `name` is a stranger's message: starts with "User Recording " and ends in .mp3 or .wav
bool isMessageFile(const String& name) {
  String lower = name; lower.toLowerCase();               // case-insensitive extension check
  bool ext = lower.endsWith(".mp3") || lower.endsWith(".wav");
  return name.startsWith(MSG_PREFIX) && ext && !name.startsWith(".");
}

// Bare file name of one directory entry (the SD library sometimes returns the full path)
String bareName(File& e) {
  String name = e.name();
  int slash = name.lastIndexOf('/');
  return slash >= 0 ? name.substring(slash + 1) : name;
}

// Folder for the current language's messages, e.g. "/ai prototype audios/hi/"
String langDir() { return String(AUDIO_DIR) + lang + "/"; }

// Open a folder. The SD driver refuses a path that ends in "/", so strip it first.
File openDir(String path) {
  while (path.length() > 1 && path.endsWith("/")) path.remove(path.length() - 1);
  File d = SD_MMC.open(path);
  if (!d || !d.isDirectory()) Serial.printf("folder not found: %s\n", path.c_str());
  return d;
}
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
void loop() {
  if (lifted()) {                                         // handset picked up
    session();                                            // run one complete call
    SD_MMC.remove("/tmp/take.wav");                       // make sure no scratch recording survives
    kit.end();                                            // make sure the codec is released
    while (lifted()) delay(50);                           // if still off the cradle, wait until it is put down
    logEvent("hangup");
    delay(300);                                           // settle before the next lift can start
  }
  delay(20);                                              // idle poll
}

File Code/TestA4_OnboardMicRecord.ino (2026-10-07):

// TEST A4 — Codec input: record 5 s from the board's OWN onboard mics to the SD card, then play it back
// Connect: USB (UART) + headphones in PHONE jack + microSD (FAT32) in the slot, DIP switches CMD and DATA3 ON.
// Libraries: arduino-audio-tools + arduino-audio-driver.
// Pass:    after "Playing back" you hear what you said. Proves record AND playback with no external parts.

#include "AudioTools.h"                                   // audio framework
#include "AudioTools/AudioLibs/AudioBoardStream.h"        // Audio Kit / ES8388 driver
#include "SD_MMC.h"                                       // ESP32's built-in SD card driver (SDMMC bus, not SPI)

AudioBoardStream kit(AudioKitEs8388V1);                   // the board / codec object

void setup() {                                            // runs once; the whole test lives here
  Serial.begin(115200);                                   // open serial
  delay(300);                                             // settle
  Serial.println("TEST A4: onboard mic record + playback");  // banner

  if (!SD_MMC.begin("/sdcard", true)) {                   // mount the SD card; `true` = 1-bit mode (leaves GPIO13/KEY2 free)
    Serial.println("SD mount FAILED - card in? DIP CMD+DATA3 ON? FAT32?");  // explain the likely cause
    return;                                               // stop the test here
  }

  // ---------- RECORD ----------
  auto rx = kit.defaultConfig(RX_MODE);                   // config for receive (recording) mode
  rx.sd_active = false;                                   // the driver must not touch SD pins - we handle SD ourselves
  rx.input_device = ADC_INPUT_LINE2;                      // LINE2 = the onboard microphones on the v2.2 board
  rx.sample_rate = 16000;                                 // 16 kHz is plenty for voice and keeps files small
  rx.channels = 1;                                        // mono
  rx.bits_per_sample = 16;                                // 16-bit samples
  kit.begin(rx);                                          // start the codec in record mode

  SD_MMC.remove("/rec.wav");                              // delete any old recording so the file starts fresh
  File f = SD_MMC.open("/rec.wav", FILE_WRITE);           // open the output file for writing
  WAVEncoder enc;                                         // encoder that writes a proper WAV header + raw samples
  EncodedAudioStream out(&f, &enc);                       // output stream = file + WAV encoder
  out.begin(rx);                                          // tell the encoder the sample format so the header is right
  StreamCopy rec(out, kit);                               // copier: from the codec (mic) into the WAV file

  Serial.println("Recording 5 seconds - talk at the board now");  // prompt the tester
  unsigned long t0 = millis();                            // remember the start time
  while (millis() - t0 < 5000) {                          // for five seconds...
    rec.copy();                                           // ...keep moving mic samples into the file
  }
  out.end();                                              // finalise the WAV header with the real length
  f.close();                                              // close the file so it is safely on the card
  kit.end();                                              // stop the codec so we can restart it in playback mode

  // ---------- PLAY BACK ----------
  Serial.println("Playing back...");                      // tell the tester what is happening
  f = SD_MMC.open("/rec.wav");                            // reopen the recording for reading
  auto tx = kit.defaultConfig(TX_MODE);                   // config for transmit (playback) mode
  tx.sd_active = false;                                   // again, driver leaves SD pins alone
  tx.sample_rate = 16000;                                 // must match the recording
  tx.channels = 1;                                        // mono, as recorded
  tx.bits_per_sample = 16;                                // 16-bit, as recorded
  kit.begin(tx);                                          // start the codec in playback mode
  kit.setVolume(0.8);                                     // 80 % volume
  WAVDecoder dec;                                         // decoder that reads the WAV header and hands out samples
  EncodedAudioStream in(&f, &dec);                        // input stream = file + WAV decoder
  in.begin();                                             // parse the header
  StreamCopy play(kit, in);                               // copier: from the file into the codec (headphones)
  while (play.copy()) {                                   // copy until the file is finished (copy() returns 0 at the end)
  }
  f.close();                                              // close the file
  kit.end();                                              // stop the codec
  SD_MMC.end();                                           // unmount the card
  Serial.println("Done. PASS if you heard yourself clearly.");  // final verdict line
}

void loop() {                                             // nothing to do after setup()
  delay(1000);                                            // idle
}
